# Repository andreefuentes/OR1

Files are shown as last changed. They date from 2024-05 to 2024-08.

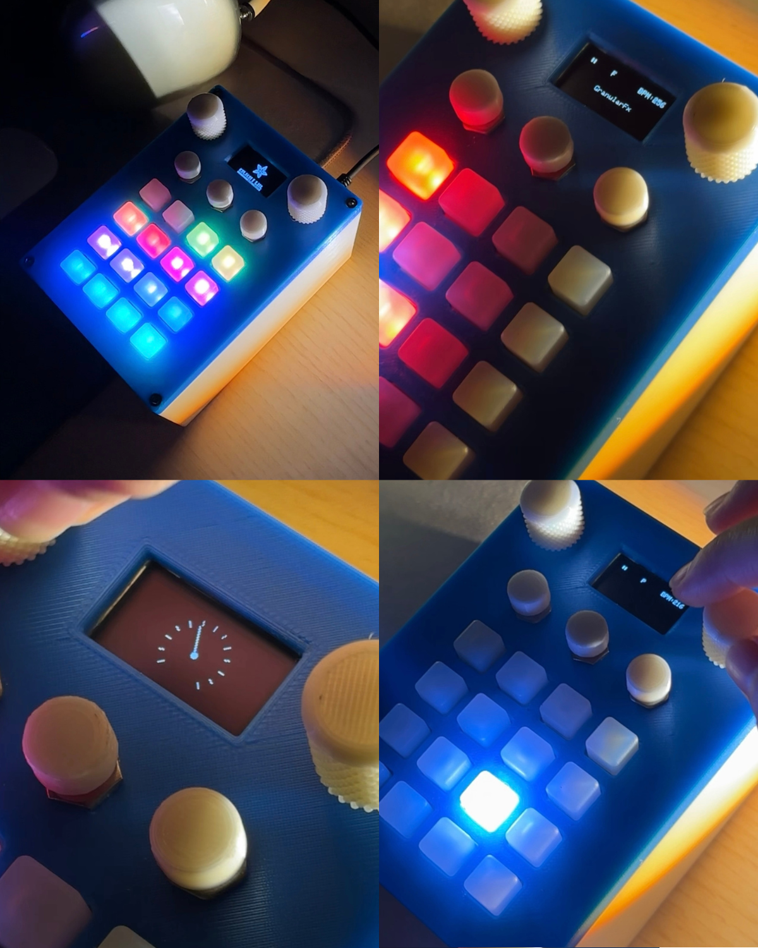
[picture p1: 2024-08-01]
OR-1 corregido.png

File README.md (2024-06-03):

# OR-1: OPEN SOURCE EDUCATIONAL KIT 2024

Este proyecto es una máquina de ritmos construida utilizando un microcontrolador Teensy 4.1 y el Audio Shield Rev D. Reproduce muestras de audio desde una tarjeta SD y envía el audio a través de USB y un DAC analógico. El Teensy está configurado para actuar como un dispositivo de audio USB, permitiendo una salida de audio de alta calidad, adecuada para grabación, transmisión en vivo o procesamiento con software de audio digital.

## Características

- **Reproducción de Audio**: Reproduce archivos WAV almacenados en una tarjeta SD.
- **Salida de Audio USB**: Envía audio directamente a una computadora vía USB.
- **Salida de Audio Analógica**: Salida opcional a un DAC analógico.
- **Interfaz de Usuario**: Controla la máquina de ritmos utilizando botones pulsadores y encoders.
- **Pantalla OLED**: Muestra el estado actual y los ajustes.
- **Carcasa Impresa en 3D**: Carcasa personalizada y accesorios para botones pulsadores.
- **Diseño de PCB**: Esquemático y archivos para la fabricación del PCB.

## Requisitos de Hardware

- Teensy 4.1 (o compatible)
- Audio Shield REV D (opcional para salida analógica)
- Tarjeta MicroSD 
- 3 Botones pulsadores
- 2 Encoders KY-040
- Adafruit NeoTrellis 4x4
- Pantalla OLED Adafruit SSD1306

## Configuración de Pines

- **Tarjeta SD**:
  - CS: Pin 10
  - MOSI: Pin 7
  - SCK: Pin 14
- **Botones Pulsadores**:
  - Botón de Programación: Pin 41
  - Botón de Repetición: Pin 40
  - Botón de Inicio/Parada: Pin 39
  - Botón de Efectos: Pin 28
- **Encoders**:
  - Encoder Principal: Pines 31, 32
  - Encoder de Efectos: Pines 29, 30
- **Dispositivos I2C**:
  - NeoTrellis: Dirección 0x2F
  - Pantalla OLED: Dirección I2C por defecto (0x3C)

## Requisitos de Software

- Arduino IDE con Teensyduino
- Bibliotecas Adafruit GFX y SSD1306
- Bibliotecas Audio, Wire, SPI, SD y SerialFlash

## Configuración

1. **Instalar Arduino IDE y Teensyduino**:
   - Descarga e instala el [Arduino IDE](https://www.arduino.cc/en/software).
   - Instala [Teensyduino](https://www.pjrc.com/teensy/teensyduino.html) para agregar soporte para Teensy al Arduino IDE.

2. **Instalar Bibliotecas Requeridas**:
   - Abre el Arduino IDE.
   - Ve a **Sketch > Include Library > Manage Libraries**.
   - Instala las bibliotecas Adafruit GFX y Adafruit SSD1306.
   - Instala la biblioteca Encoder, Adafruit_Neotrellis
   - Asegúrate de que las bibliotecas Audio, Wire, SPI, SD y SerialFlash estén instaladas.

3. **Configurar el Teensy**:
   - Ve a **Tools > Board** y selecciona tu modelo de Teensy.
   - Ve a **Tools > USB Type** y selecciona **Audio**.

4. **Conectar el Hardware**:
   - Conecta los botones pulsadores, encoders, NeoTrellis y la pantalla OLED según la configuración de pines.
   - Inserta la tarjeta SD con tus archivos WAV.

5. **Subir el Código**:
   - Abre el archivo `Or-1.ino` en el Arduino IDE.
   - Haz clic en **Upload** para programar el Teensy.

## Uso

- **Reproducción de Audio**:
  - La máquina de ritmos reproducirá automáticamente los archivos de audio listados en el código (`SD.WAV`, `BD.WAV`, `CY.WAV`, etc.). Puedes subir nuevos samples y cambiar los nombres en el código fuente para reproducir tus samples. 
  - Usa los botones pulsadores para controlar la reproducción y cambiar modos.
  - Los encoders te permiten ajustar el BPM y los parámetros de los efectos.

- **Audio USB**:
  - Conecta el Teensy a tu computadora vía USB.
  - El Teensy debería aparecer como un dispositivo de audio en tu computadora.
  - Puedes usar software de grabación para capturar la salida de audio del Teensy.

- **Salida de Audio por I2S**:
  - Para utilizar la salida de audio por I2S en el jack de audífonos, descomenta las líneas correspondientes en el código.

## Archivos Incluidos

- **Modelo 3D**: Archivos STL para imprimir la carcasa y los accesorios para los botones pulsadores.
- **Diseño de PCB**: Esquemático y archivos Gerber para la fabricación del PCB.
- **Guia de construcción**: Guia de ensamblaje para la replicación de la máquina. 

## Resolución de Problemas

- **Sin Sonido**:
  - Asegúrate de que el Teensy esté configurado para Audio USB en el Arduino IDE.
  - Verifica las conexiones a la tarjeta SD y asegúrate de que los archivos WAV estén en el formato correcto.
  - Asegúrate de que la asignación de `AudioMemory()` sea suficiente.

- **Audio Distorsionado**:
  - Esto puede ocurrir en macOS. Consulta el [foro de Teensy](https://forum.pjrc.com/threads/34855-Distorted-audio-when-using-USB-input-on-Teensy-3-1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) para posibles soluciones.

## Licencia

Este proyecto está licenciado bajo la Licencia MIT. Consulta el archivo [LICENSE](LICENSE) para más detalles.

## Contribuciones

¡Las contribuciones son bienvenidas! Por favor, haz un fork de este repositorio y envía pull requests.

## Agradecimientos

- Agradecimientos especiales a [PJRC](https://www.pjrc.com/) por la plataforma Teensy.
- Bibliotecas de [Adafruit](https://www.adafruit.com/) y la comunidad de código abierto.

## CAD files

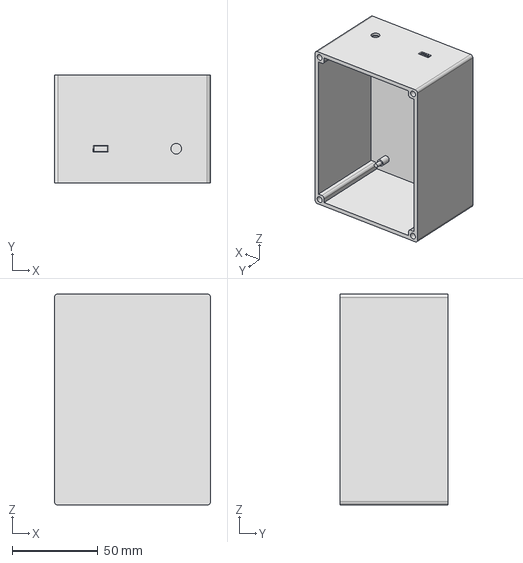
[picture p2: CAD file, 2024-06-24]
3DMODEL/mainbox_final.stp
91.0 x 63.0 x 123.0 mm

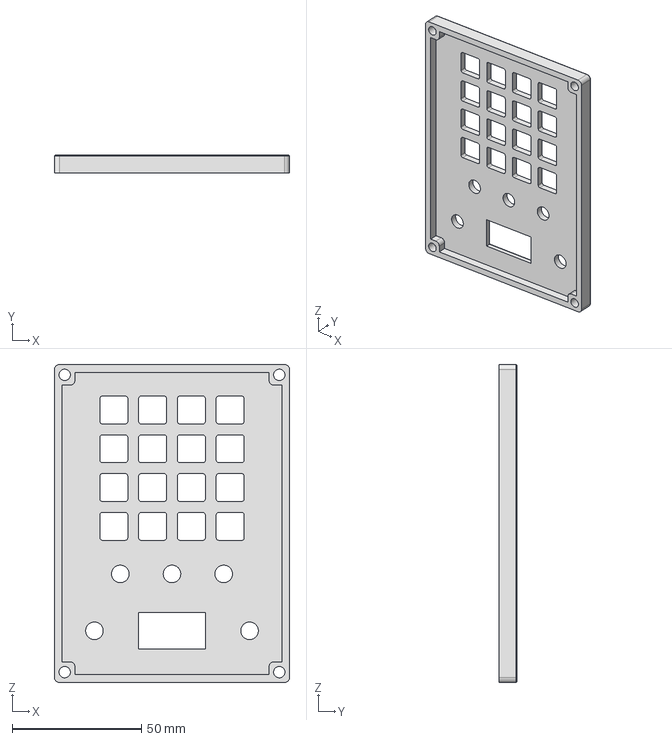
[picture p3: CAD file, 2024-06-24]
3DMODEL/mainbox_lid_final.stp
91.0 x 7.00 x 123.0 mm

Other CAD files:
3DMODEL/neotrellis_support.ipt
3DMODEL/screen_support.ipt

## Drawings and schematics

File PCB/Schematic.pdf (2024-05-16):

A | A

1

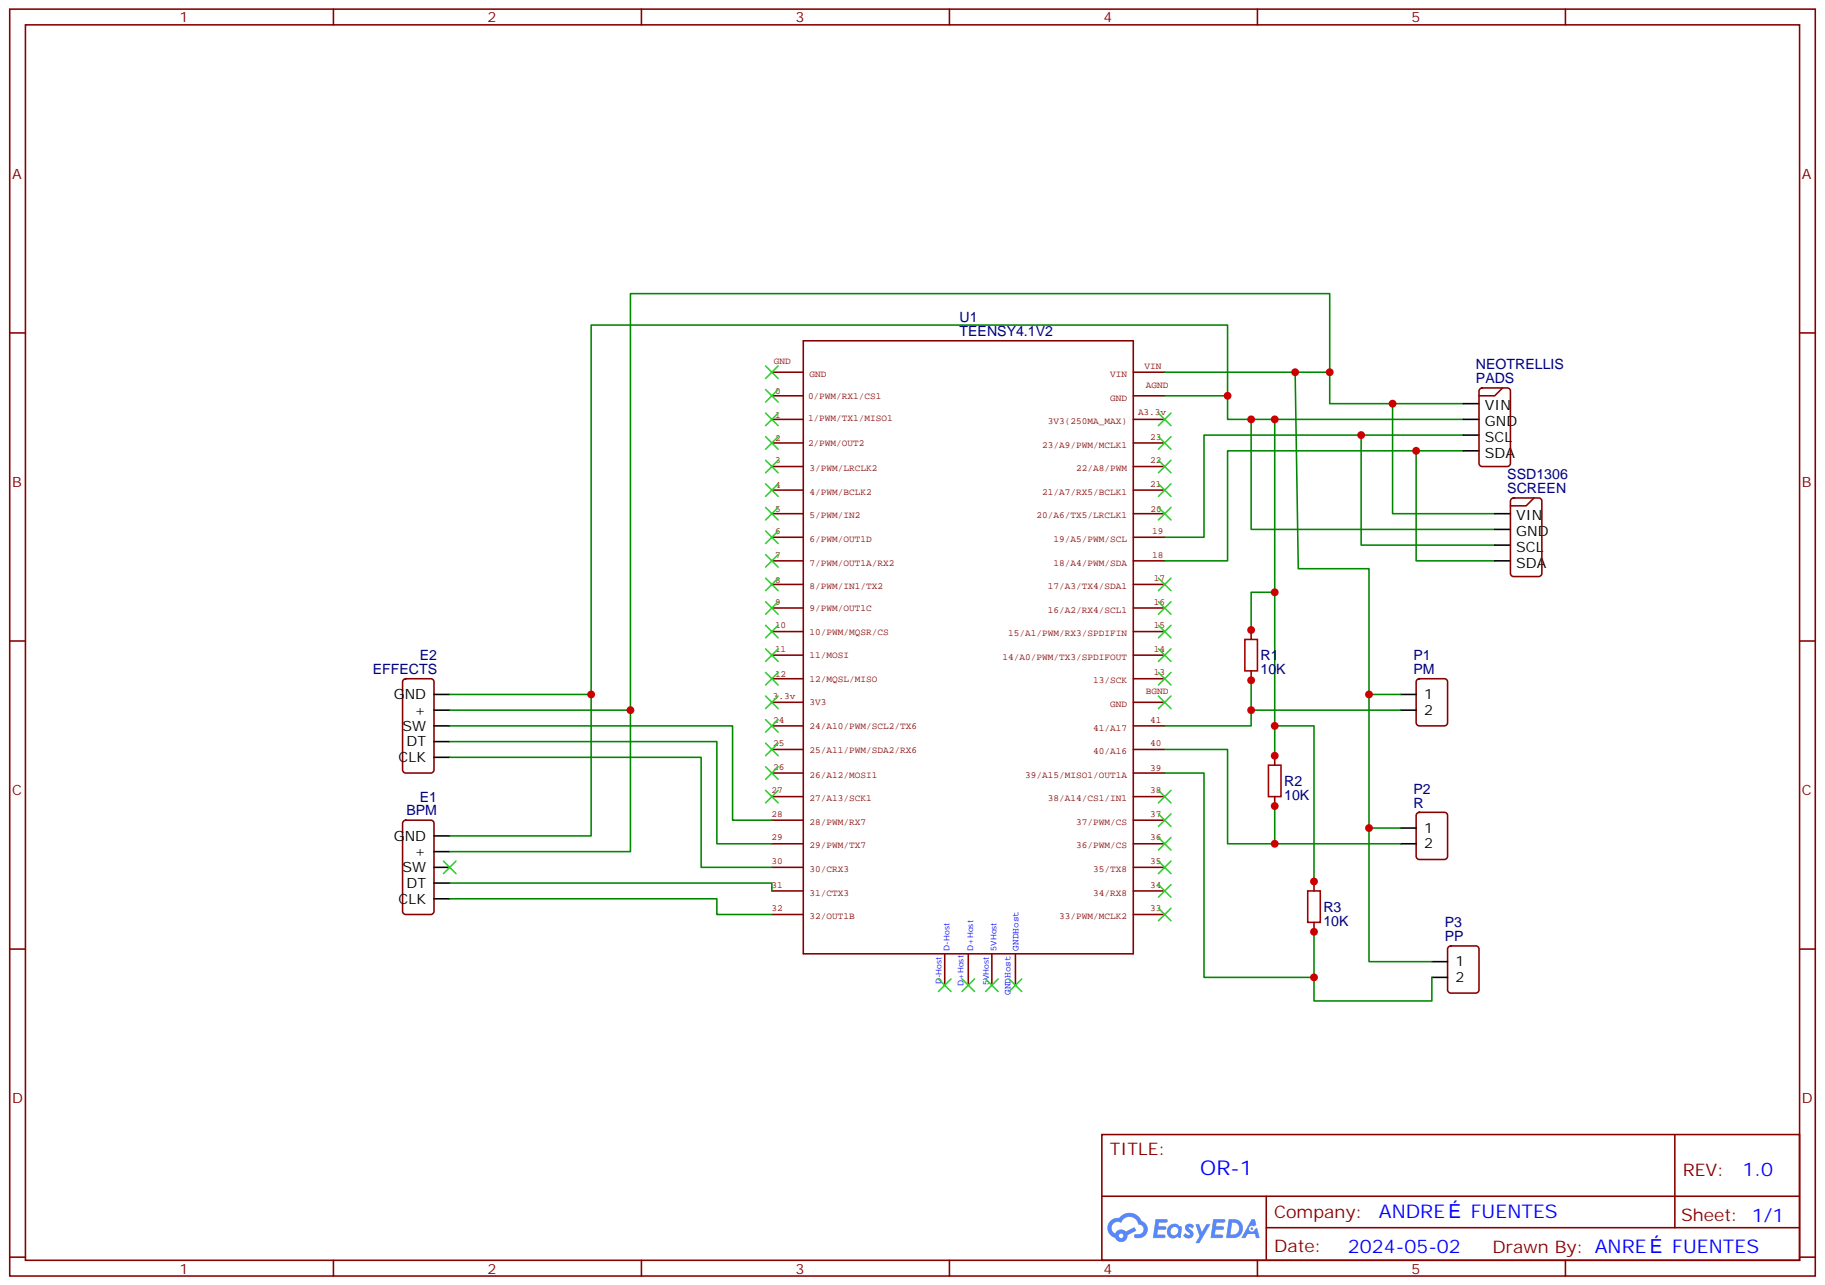
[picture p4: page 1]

Drawn By: ANRE FUENTES

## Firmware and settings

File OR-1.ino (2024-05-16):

#include <Adafruit_NeoTrellis.h>
#include <Encoder.h>
#include <Audio.h>
#include <Wire.h>
#include <SPI.h>
#include <SerialFlash.h>
#include <Adafruit_GFX.h>
#include <Adafruit_SSD1306.h>

//------------------------------------------- VARIABLES GLOBALES Y OBJETOS ---------------------------------------------

//--------------------- AUDIO ----------------------------

AudioPlaySdWav playSdWav[16]; // objetos de audio para almacenar samples 
AudioOutputI2S i2s1; // habilitar comunicación i2s para audio 
AudioMixer4 mixer1, mixer2, mixer3, mixer4, sampleMixer, effectMixer1, effectMixer2, effectMixer3, outputMixer; // objetos para la cadena de audio 

//Utilizado para la salida USB
AudioOutputUSB usbaudio; 
AudioOutputAnalog dac;
AudioConnection *patchCords[36]; // conexiones para la cadena de audio 
AudioControlSGTL5000 sgtl5000_1; 

// Audio FX
AudioFilterStateVariable hpFilter; //objeto de filtro

AudioEffectGranular      granular1; // objeto de efecto

// definición de pin de acceso a tarjeta SD con samples en teensy AB
#define SDCARD_CS_PIN 10
#define GRANULAR_MEMORY_SIZE 12800
int16_t granularMemory[GRANULAR_MEMORY_SIZE];

// Samples de Audio
// de utilizar otros samples, el formato es en MAYUSCULAS.WAV
const char* sampleFiles[16] = {"BD.WAV", "CB.WAV", "CH.WAV", "CL.WAV", "CP.WAV", "CY.WAV", "HC.WAV", "HT.WAV", "LC.WAV", "LT.WAV", "MA.WAV", "MC.WAV", "MT.WAV", "OH.WAV", "RS.WAV", "SD.WAV"};

/// variables para filtros
float hpFilterFreq = 100.0;  // Start at 100 Hz
int hpFilterStep = 0; // filtro pasa altas HPF inicializado en 0
const int maxSteps = 100;  // numero maximo de steps del filtro 
float hpFilterDryWet; // dry/wet para HPF

int granularFxStep = 0; // step inicial 0 para efecto granular
float granularFxWetDry = granularFxStep / 10.0; // wet/dry logic de efecto granular

// volumen inicial 
float masterVolume = 0.8;
// steps y playback 

unsigned long lastPlaybackTime = 0; // almacenamiento de la ultima reproducción de un sonido 


//--------------------- TRELLIS ----------------------------
Adafruit_NeoTrellis trellis(0x2F);
//duración de blink al seleccionar samples
const uint32_t blinkDuration = 500; // duracion del parpadeo de LEDs al seleccionar un sample en ms
uint32_t colors[16]; // almacena los colores asignados a cada pad del trellis
int sequencerSteps[16] = {0}; //array que guarda los pasos del secuenciador indicando qué sample se reproduce en cada paso
//otras variables
int repeatPadNum = -1; // indica el numero de pad que se repite 
int selectedSample = -1; // indica el número de sample seleccionado
unsigned long lastStepTime = 0; // alacenamiento de ultimo step del secuenciador


//--------------------- ENCODERS ----------------------------
#define EFFECTS_BUTTON_PIN 28 // pin asignado para el botón de control de selección  de efectos 
Encoder bpmEncoder(31, 32); // control de BPM
Encoder effectsEncoder(29, 30); // control de efectos 
int lastbpmEncoderPosition = 0; //almacena ultima posición para detectar cambios
int lastEffectsEncoderPosition = 0; //almacena ultima posición para detectar cambios
int BPM = 120; // bpm inicial
bool lastEffectsButtonState = HIGH; //
unsigned long MS_PER_BEAT = 60000 / BPM; // conversión de bpm a ms
//estados iniciales de funciones
bool adjustingFx = false; // indica si el sistema está actualmente ajustando el volumen o efecto o filtro 
int activeFx = -1; // mantiene el índice del volumen efecto o filtro activo para saber qué se está modificando

//--------------------- PANTALLA ----------------------------
#define SCREEN_WIDTH 128 
#define SCREEN_HEIGHT 64
#define OLED_RESET    -1
Adafruit_SSD1306 display(SCREEN_WIDTH, SCREEN_HEIGHT, &Wire, OLED_RESET);

//--------------------- BOTONES ----------------------------
#define PROGRAM_BUTTON_PIN 41 //pin para boton de program/freeplay
#define REPEAT_BUTTON_PIN 40 // pin para boton de repeatmode
#define START_STOP_BUTTON_PIN 39 // boton de play/pausa 
bool lastProgramButtonState = HIGH; 
bool lastStartStopButtonState = HIGH;

//banderas para saber qué función está activa 
bool repeatMode = false;
bool programMode = false;
bool isPlaying = true;

//--------------------- MENU ----------------------------
unsigned long lastMenuItemChange = 0; //guarda tiempo desde el ultimo cambio en el item del menu 
const unsigned long menuItemDisplayDuration = 2000; // 2s que se despliega el item del menu en la pantalla 
const char* fxMenuItems[] = {"Volume", "High-Pass", "GranularFx"}; //array de items en el menu
int numItems = sizeof(fxMenuItems) / sizeof(fxMenuItems[0]); //calcula el número de items en el array
int currentMenuItem = 0; //indica que se ha seleccionado en el menu

//------------------------------------------------------- FUNCIONES ----------------------------------------------------------------------


//------------------------------------------- SETUP DE HARDWARE --------------------------------------------
// SetUp inicializa el hardware y las conexiones de audio
void setup() {
    Serial.begin(9600);
    initializeHardware();
    initializeAudioConnections();
}


//inicialización de hardware: MicroSD de Audio Board, Pantalla y NeoTrellis
void initializeHardware() {
    AudioMemory(50);
    sgtl5000_1.enable();
    sgtl5000_1.volume(0.7);

    //screen setup
  if(!display.begin(SSD1306_SWITCHCAPVCC, 0x3C)) { // DIRECCION I2C 0x3C PARA SSD1306
  Serial.println(F("SSD1306 allocation failed"));
  for(;;);
  }
  
  display.display();
  delay(2000); 

  // limpieza de buffer
  display.clearDisplay();
  //inicialización neotrellis 
  trellis.begin();
    assignColors();
    for (int i = 0; i < NEO_TRELLIS_NUM_KEYS; i++) {
        trellis.activateKey(i, SEESAW_KEYPAD_EDGE_RISING);
        trellis.registerCallback(i, keyEventCallback);
    }
    startupAnimation();
    
    // inicialización de pines para botones con resistencia pullup
    pinMode(PROGRAM_BUTTON_PIN, INPUT_PULLDOWN);
    pinMode(EFFECTS_BUTTON_PIN, INPUT_PULLDOWN);
    pinMode(REPEAT_BUTTON_PIN, INPUT_PULLDOWN);
    pinMode(START_STOP_BUTTON_PIN, INPUT_PULLDOWN);  
}

// Inicialización de conexiones de Audio 
void initializeAudioConnections() {

  granular1.begin(granularMemory, GRANULAR_MEMORY_SIZE); 

    if (!SD.begin(SDCARD_CS_PIN)) {
        Serial.println("Unable to access the SD card");
        while (1) delay(500);
    }


  for (int i = 0; i < 4; i++) { 
        mixer1.gain(i, 0.75); // gain inicial de mixers
        mixer2.gain(i, 0.75); // 
        mixer3.gain(i, 0.75); // 
        mixer4.gain(i, 0.75); // 
    }

    // Set gains para los mixers de samples
    sampleMixer.gain(0, 1.0);
    sampleMixer.gain(1, 1.0);
    sampleMixer.gain(2, 1.0);
    sampleMixer.gain(3, 1.0);

    // Ejemplo para setear los gains del mixer de efectos 
    effectMixer1.gain(0, hpFilterDryWet);
    effectMixer1.gain(1, 1.0 - hpFilterDryWet);

    effectMixer2.gain(0, granularFxWetDry);
    effectMixer2.gain(1, 1.0 - granularFxWetDry);

    // Ajustar el gain del output inicial 
    outputMixer.gain(0,0.5);



    //patcheo de conexiones de audio a los mixers iniciales, uno para cada fila del secuenciador (4 samples)
    for (int i = 0; i < 4; i++) {
        patchCords[i] = new AudioConnection(playSdWav[i], 0, mixer1, i);
    }
    for (int i = 4; i < 8; i++) {
        patchCords[i] = new AudioConnection(playSdWav[i], 0, mixer2, i - 4);
    }
    for (int i = 8; i < 12; i++) {
        patchCords[i] = new AudioConnection(playSdWav[i], 0, mixer3, i - 8);
    }
    for (int i = 12; i < 16; i++) {
        patchCords[i] = new AudioConnection(playSdWav[i], 0, mixer4, i - 12);
    }
    //patcheo de todos los samples en sus mixers para tenerlos en una sola salida 
    patchCords[16] = new AudioConnection(mixer1, 0, sampleMixer, 0);
    patchCords[17] = new AudioConnection(mixer2, 0, sampleMixer, 1);
    patchCords[18] = new AudioConnection(mixer3, 0, sampleMixer, 2);
    patchCords[19] = new AudioConnection(mixer4, 0, sampleMixer, 3);

    //PATCHEO GRANULAR
    patchCords[20] = new AudioConnection(sampleMixer, granular1); 
    patchCords[21] = new AudioConnection(sampleMixer, 0, effectMixer1, 1);
    patchCords[22] = new AudioConnection(granular1, 0, effectMixer1, 0);
    
    //PATCHEO HPF
    patchCords[23] = new AudioConnection(effectMixer1, 0, hpFilter, 0);
    patchCords[24] = new AudioConnection(hpFilter, 2, effectMixer2, 0);

    //HPF Y GRANULAR A MIXER 2
    patchCords[25] = new AudioConnection(effectMixer1, 0, effectMixer2, 1);

    // MIXER A OUTPUT MIXER
    patchCords[26] = new AudioConnection(effectMixer2, 0, outputMixer, 0);

    //OUTPUT MIXER A USBAUDIO POR DEFAULT
    patchCords[27] = new AudioConnection(outputMixer, 0, usbAudio, 0);
    patchCords[28] = new AudioConnection(outputMixer, 0, usbAudio, 1);
    patchCords[29] = new AudioConnection(outputMixer, 0, dac, 0);

    /* DESCOMENTAR SI SE DESEA UTILIZAR LA SALIDA DE AUDIFONOS 3.5MM
    // OUTPUT MIXER A I2S STEREO DEL AUDIO BOARD
    patchCords[31] = new AudioConnection(effectMixer1, 0, outputMixer, 0);
    patchCords[27] = new AudioConnection(outputMixer, 0, i2s1, 0);
    patchCords[28] = new AudioConnection(outputMixer, 0, i2s1, 1);
  */
}

//función de asignación de colores a cada pad
void assignColors() {
    colors[0] = trellis.pixels.Color(255, 0, 0); // Red
    colors[1] = trellis.pixels.Color(0, 255, 0); // Green
    colors[2] = trellis.pixels.Color(0, 0, 255); // Blue
    colors[3] = trellis.pixels.Color(255, 255, 0); // Yellow
    colors[4] = trellis.pixels.Color(0, 255, 255); // Cyan
    colors[5] = trellis.pixels.Color(255, 0, 255); // Magenta
    colors[6] = trellis.pixels.Color(255, 165, 0); // Orange
    colors[7] = trellis.pixels.Color(128, 0, 128); // Purple
    colors[8] = trellis.pixels.Color(255, 192, 203); // Pink
    colors[9] = trellis.pixels.Color(128, 128, 0); // Olive
    colors[10] = trellis.pixels.Color(0, 128, 0); // Dark Green
    colors[11] = trellis.pixels.Color(128, 0, 0); // Maroon
    colors[12] = trellis.pixels.Color(0, 128, 128); // Teal
    colors[13] = trellis.pixels.Color(0, 0, 128); // Navy
    colors[14] = trellis.pixels.Color(139, 69, 19); // Saddle Brown
    colors[15] = trellis.pixels.Color(75, 0, 130); // Indigo
}


//------------------------------------------- MANEJO DE INTERFAZ DE USUARIO --------------------------------------------
// función para cambiar entre program mode y freeplay mode
void toggleProgramMode() { 
    bool newProgramButtonState = digitalRead(PROGRAM_BUTTON_PIN);
    if (newProgramButtonState != lastProgramButtonState && newProgramButtonState == LOW) { //detecta cambio de estado
        programMode = !programMode;
        selectedSample = -1;  // RESETEA EL SAMPLE SELECCIONADO 
        Serial.println(programMode ? "Programming Mode" : "Free Play Mode"); //debug en serial 
    }
    lastProgramButtonState = newProgramButtonState;
}
// función para play / pause
void toggleStartStop() { 
    bool newStartStopButtonState = digitalRead(START_STOP_BUTTON_PIN);
    if (newStartStopButtonState != lastStartStopButtonState && newStartStopButtonState == LOW) { //detecta cambio de estado
        isPlaying = !isPlaying; 
        if (!isPlaying) {
            for (int i = 0; i < 16; ++i) {
                playSdWav[i].stop();
            }
        }
        delay(300); // Debounce delay
        Serial.println(isPlaying ? "Sequencer Resumed" : "Sequencer Paused");
    }
    lastStartStopButtonState = newStartStopButtonState;
}

//función para ajustar BPM 
void handleBpmAdjustment() { 
    int currentbpmEncoderPosition = bpmEncoder.read();
    if (currentbpmEncoderPosition != lastbpmEncoderPosition) {
        int encoderChange = currentbpmEncoderPosition - lastbpmEncoderPosition;
        BPM += encoderChange; // detecta cambios en el encoder para determinar el nuevo BPM
        BPM = constrain(BPM, 30, 300); // incremento de 30 debido al encoder KY040
        MS_PER_BEAT = 60000 / BPM;
        lastbpmEncoderPosition = currentbpmEncoderPosition;
        Serial.print("BPM: ");
        Serial.println(BPM);
    }
}

// función para selección de volumen, filtro o efecto
void toggleFxAdjustmentMode() { 
    bool currentEffectsButtonState = digitalRead(EFFECTS_BUTTON_PIN);
    if (currentEffectsButtonState == LOW && lastEffectsButtonState == HIGH) {  //lee el estado anterior para determinar si cambia
        adjustingFx = !adjustingFx;
        if (adjustingFx) {
            activeFx = currentMenuItem;
            Serial.print("Adjusting: ");
            Serial.println(fxMenuItems[currentMenuItem]);
        } else {
            activeFx = -1;
            Serial.println("Adjustment mode exited");
        }
    }
    lastEffectsButtonState = currentEffectsButtonState;
}

//manejo del encoder de efectos y su menu 
void handleEffectsEncoder() {
    static int effectsDetentCounter = 0;
    int currentEffectsEncoderPosition = effectsEncoder.read();

    if (currentEffectsEncoderPosition != lastEffectsEncoderPosition) {
        int encoderChange = currentEffectsEncoderPosition - lastEffectsEncoderPosition;
        effectsDetentCounter += abs(encoderChange);  // Contador del incremento por el cambio absoluto por encoder KY040 
        if (effectsDetentCounter >= 4) {  // Usando 4 como un threshold del dent para menos sensibilidad del encoder para navegación en el menu
            effectsDetentCounter = 0; 
            int menuChange = (encoderChange > 0) ? 1 : -1; 
            currentMenuItem += menuChange;
            currentMenuItem = (currentMenuItem + numItems) % numItems; // darle vuelta al menu de selección cuando se llega al ultimo elemento

            if (!adjustingFx) {
                displayMenu();  // llama funcion de display
                lastMenuItemChange = millis(); // cambia el timestamp al cambiar la seleccion en el menu
            } else if (adjustingFx && activeFx == currentMenuItem) {
                lastMenuItemChange = millis();
                adjustFxParameter(menuChange);
            }
        }

        lastEffectsEncoderPosition = currentEffectsEncoderPosition; // actualiza la ultima posición para la próxima llamada
    }
}

//detección de pad y activación de color
void togglePadState(int padNum) {
    if (sequencerSteps[padNum] == 0) {
        sequencerSteps[padNum] = selectedSample + 1;
        trellis.pixels.setPixelColor(padNum, colors[selectedSample]);
    } else {
        sequencerSteps[padNum] = 0;
        trellis.pixels.setPixelColor(padNum, 0);
    }
    trellis.pixels.show();
}

//para la constante lectura de entradas en el trellis
void pollTrellis() { 
    trellis.read();
}

// manejo de trellis Y modos programing/freeplay y play/pause
TrellisCallback keyEventCallback(keyEvent evt) {
    int padNum = evt.bit.NUM;  // identifica el numero de pad 

    if (evt.bit.EDGE == SEESAW_KEYPAD_EDGE_RISING && padNum >= 0 && padNum < 16) { // identifica eventos del pad
        Serial.println("Edge Rising Detected");

        if (!programMode) { // Modo Freeplay
            if (digitalRead(REPEAT_BUTTON_PIN) == HIGH) {
                // si se presiona el botón de repetición, repetir sample
                repeatMode = true; 
                Serial.println("Repeat Mode Activated"); //debuggeo en serial 
                repeatPadNum = padNum;  // marca el pad para repetición
            } else if (digitalRead(REPEAT_BUTTON_PIN) == LOW){
                // si no se presiona el boton repeat, solo se reproduce una vez 
                repeatMode = false; 
                playSdWav[padNum].stop();
                playSdWav[padNum].play(sampleFiles[padNum]);
                Serial.println("Playing Sample Once");
                //activación de color momentánea
                trellis.pixels.setPixelColor(padNum, colors[padNum]);
                trellis.pixels.show();
                delay(50); //delay para corta visibilidad del color
                trellis.pixels.setPixelColor(padNum, 0);
                trellis.pixels.show();
                repeatPadNum = -1;  // asegurar que no se active modo repetición         
            }
        } else {
            // modo de programación
            if (selectedSample == -1) {
                repeatMode = false; 
                selectedSample = padNum;
                // retroalimentación visual para sample seleccionado 
                trellis.pixels.setPixelColor(selectedSample, colors[selectedSample]);
                trellis.pixels.show();
                delay(blinkDuration);
                trellis.pixels.setPixelColor(selectedSample, 0);
                trellis.pixels.show();
            } else {
                // asignación del sample al paso seleccionado
              togglePadState(padNum);
              printArray();  // debuggeo del array del secuenciador
            }
        }
    }
    return 0;
}

//------------------------------------------- PROCESAMIENTO Y CONTROL DE AUDIO --------------------------------------------

//actualización del secuenciador 
void updateSequencer() { 
    unsigned long currentMillis = millis();
    if (isPlaying && currentMillis - lastStepTime >= MS_PER_BEAT) {
        lastStepTime = currentMillis;
        static int currentStep = 0;
        currentStep = (currentStep + 1) % 16;

        int fileIndex = sequencerSteps[currentStep] - 1;
        if (fileIndex >= 0 && fileIndex < 16) {
            playSdWav[currentStep].stop();
            playSdWav[currentStep].play(sampleFiles[fileIndex]);
        }

        // LEDS para indicar el paso del secuenciador en tiempo real
        for (int i = 0; i < 16; i++) {
            if (i == currentStep) {
                trellis.pixels.setPixelColor(i, trellis.pixels.Color(255, 255, 255));
            } else if (sequencerSteps[i] > 0) {
                uint32_t color = colors[sequencerSteps[i] - 1];
                trellis.pixels.setPixelColor(i, color);
            } else {
                trellis.pixels.setPixelColor(i, 0);
            }
        }
        trellis.pixels.show();
    }
}

// manejo del modo de repetición 
void handleRepeat() { 
    unsigned long currentMillis = millis();
    if (repeatPadNum >= 0 && digitalRead(REPEAT_BUTTON_PIN) == HIGH) {
        if (currentMillis - lastPlaybackTime >= MS_PER_BEAT) {
            playSdWav[repeatPadNum].stop();
            playSdWav[repeatPadNum].play(sampleFiles[repeatPadNum]);
            Serial.println("Repeating Sample");
            lastPlaybackTime = currentMillis;
        }
    } else if (repeatPadNum >= 0 && digitalRead(REPEAT_BUTTON_PIN) == LOW) {
        playSdWav[repeatPadNum].stop();
        Serial.println("Stopping Repeat");
        repeatPadNum = -1;
    }
}

//ajuste de volumen
void adjustVolume(int encoderChange) {
    // ajusta el volumen por incrementos 
    float volumeIncrement = 0.1; // valor de incremento de 0.1 para 10 pasos
    
    // ajuste del volumen master
    masterVolume += encoderChange * volumeIncrement;
    
    // 0 mute 1 volumen máximo
    masterVolume = constrain(masterVolume, 0, 1);
    
    // actualiza el gain 
    outputMixer.gain(0, masterVolume);

    Serial.print("Master Volume: ");
    Serial.println(masterVolume);
}

//ajuste HPF
void adjustHighPassFreq(int encoderChange) {
    
    hpFilterStep += encoderChange;
    hpFilterStep = constrain(hpFilterStep, 0, 10);  // 10 pasos 

    // calcular la frecuencia con el cambio en el encoder
    float minFreq = 100.0;
    float freqIncrement = 490.0;
    float hpFilterFreq = minFreq + (hpFilterStep * freqIncrement);

    // asignar la frecuencia
    hpFilter.frequency(hpFilterFreq);

    // control dry/wet del filtro 
    if (hpFilterStep > 1) {
        hpFilterDryWet = 100; // 
    } else {
        hpFilterDryWet = 0; // 
    }

    // aplicación del dry/wet en el mixer 
    effectMixer2.gain(0, hpFilterDryWet / 100.0);
    effectMixer2.gain(1, 1.0 - hpFilterDryWet / 100.0);

    Serial.print("Step: ");
    Serial.print(hpFilterStep);
    Serial.print(" - HP Filter Frequency: ");
    Serial.print(hpFilterFreq);
    Serial.println(" Hz");
    Serial.print("Dry/Wet Mix: ");
    Serial.print(hpFilterDryWet);
    Serial.println("%");
}

//ajuste efecto Granular
void adjustGranularFx(int encoderChange) {
    // escala el encoderchange directamente al mix wet/dry 
    granular1.beginPitchShift(55); // pitch shift establecido a 55 
    granularFxWetDry += encoderChange*5;  // cada paso cambia el mix por 1%
    granularFxWetDry = constrain(granularFxWetDry, 0, 100); // manejo de 0 a 100 

    effectMixer1.gain(0, granularFxWetDry / 100.0);
    effectMixer1.gain(1, 1.0 - granularFxWetDry / 100.0);

    Serial.print("Granular FX Dry/Wet: ");
    Serial.print(granularFxWetDry);
    Serial.println("% Wet");
}

// controla el manejo de ajustes del menu y activa la función de cada uno 
void adjustFxParameter(int encoderChange) { 
    switch (activeFx) {
        case 0:
            adjustVolume(encoderChange);
            break;
        case 1:
            adjustHighPassFreq(encoderChange);
            break;
        case 2:
            adjustGranularFx(encoderChange);
            break;
        default:
            Serial.println("No active FX to adjust");
            break;
                }
}


//------------------------------------------- FUNCIONES DE AYUDA Y VISUALIZACIÓN --------------------------------------------

void startupAnimation() {
    for (uint16_t i = 0; i < trellis.pixels.numPixels(); i++) {
        trellis.pixels.setPixelColor(i, Wheel(map(i, 0, trellis.pixels.numPixels(), 0, 255)));
        trellis.pixels.show();
        delay(50);
    }
    for (uint16_t i = 0; i < trellis.pixels.numPixels(); i++) {
        trellis.pixels.setPixelColor(i, 0x000000);
        trellis.pixels.show();
        delay(50);
    }
}
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
void loop() {
    handleBpmAdjustment();
    toggleProgramMode();
    toggleStartStop();
    updateSequencer();
    handleRepeat();
    pollTrellis();
    toggleFxAdjustmentMode();
    handleEffectsEncoder();
    updateDisplay(BPM, masterVolume, isPlaying, programMode, repeatMode, adjustingFx);
}
